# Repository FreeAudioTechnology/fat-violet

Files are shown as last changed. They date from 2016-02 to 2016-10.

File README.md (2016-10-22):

# violet
Open Source Microphone System with integrated ADC, digital phantom power, AES42, large diaphragm condenser capsule support

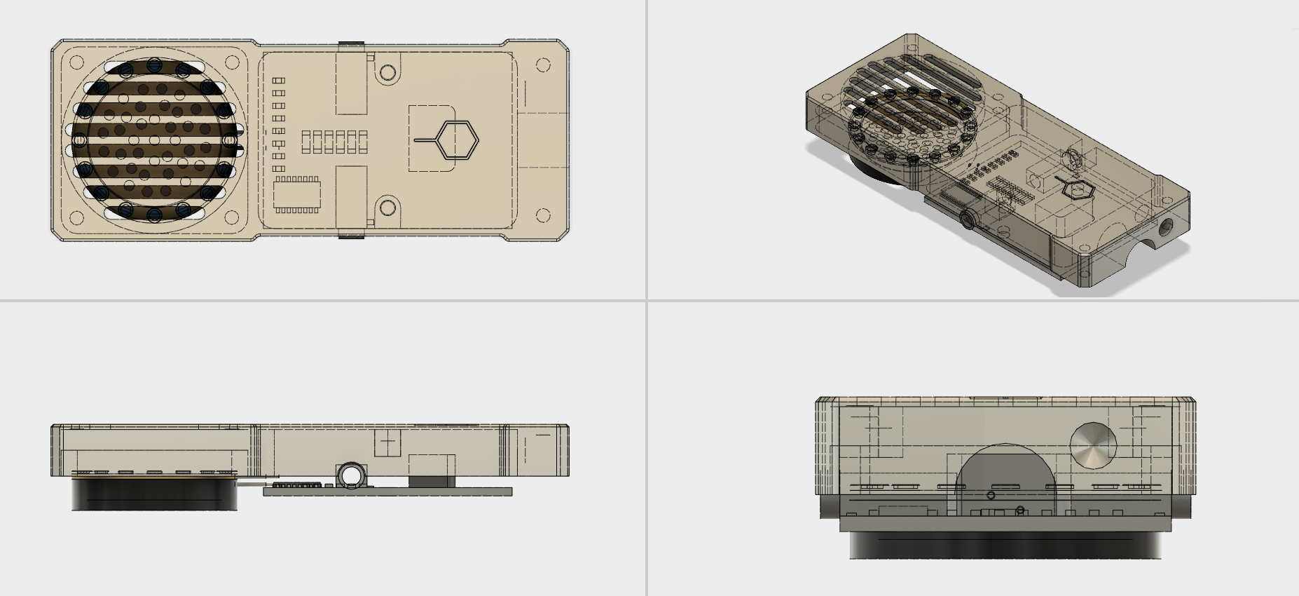
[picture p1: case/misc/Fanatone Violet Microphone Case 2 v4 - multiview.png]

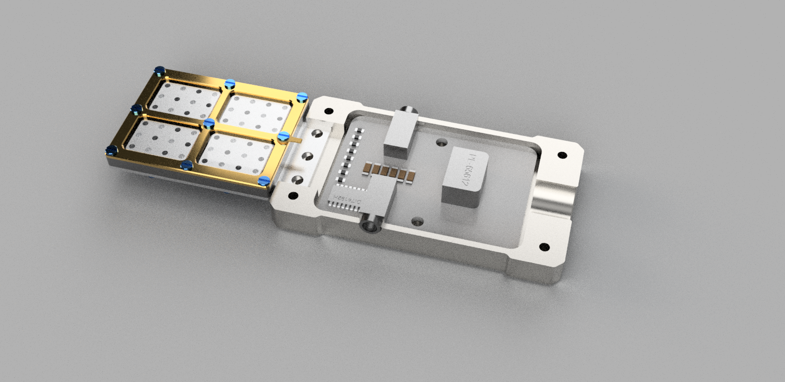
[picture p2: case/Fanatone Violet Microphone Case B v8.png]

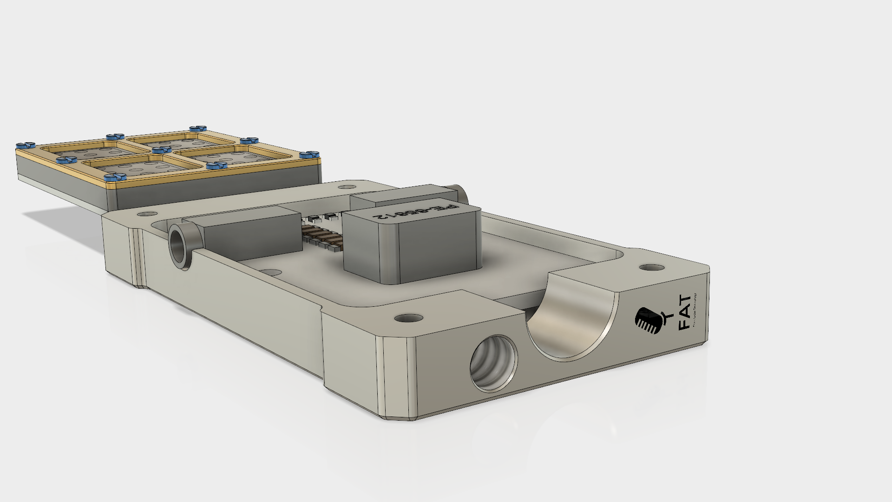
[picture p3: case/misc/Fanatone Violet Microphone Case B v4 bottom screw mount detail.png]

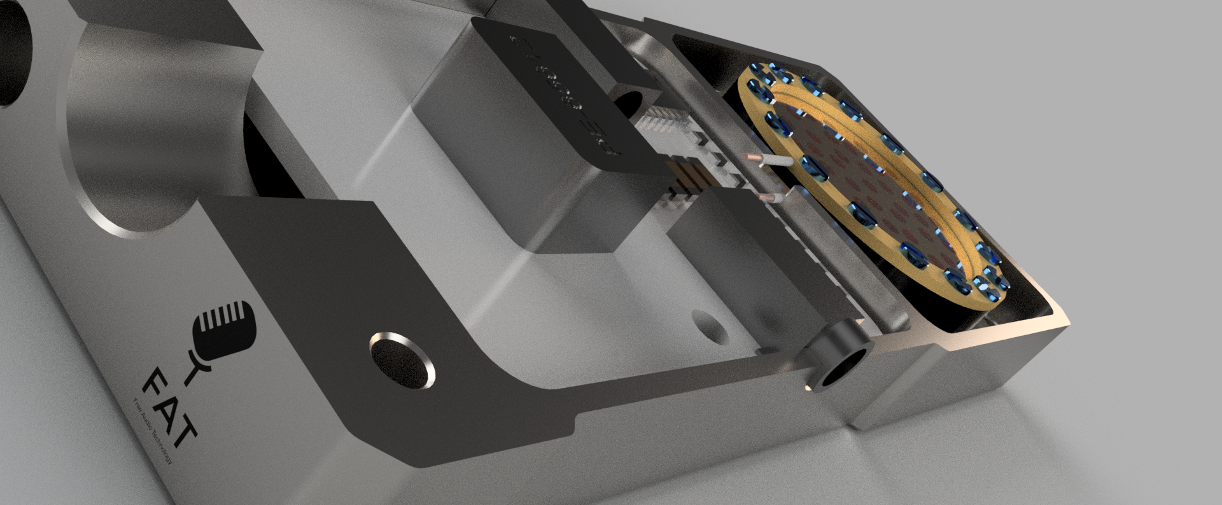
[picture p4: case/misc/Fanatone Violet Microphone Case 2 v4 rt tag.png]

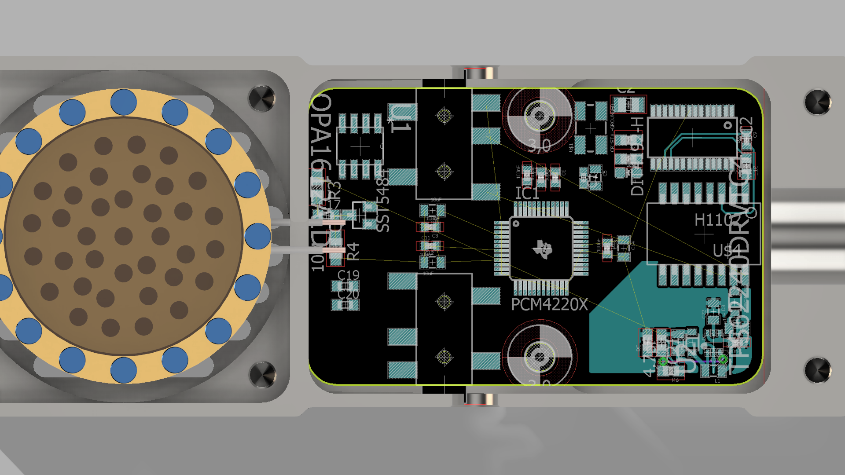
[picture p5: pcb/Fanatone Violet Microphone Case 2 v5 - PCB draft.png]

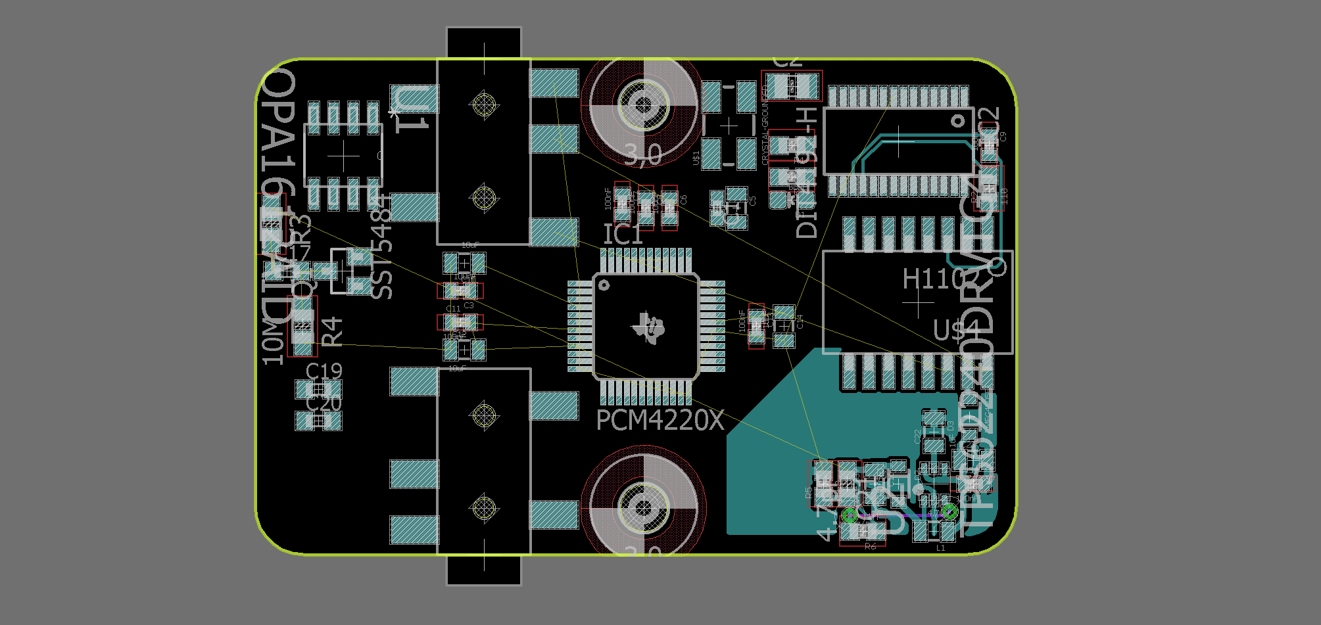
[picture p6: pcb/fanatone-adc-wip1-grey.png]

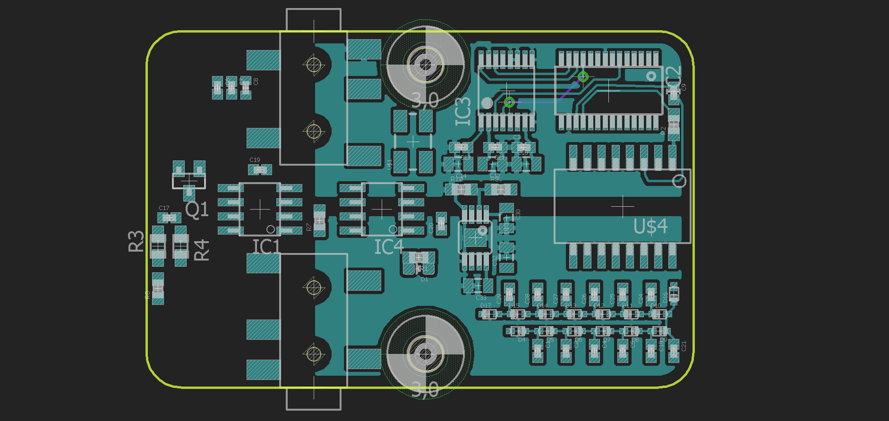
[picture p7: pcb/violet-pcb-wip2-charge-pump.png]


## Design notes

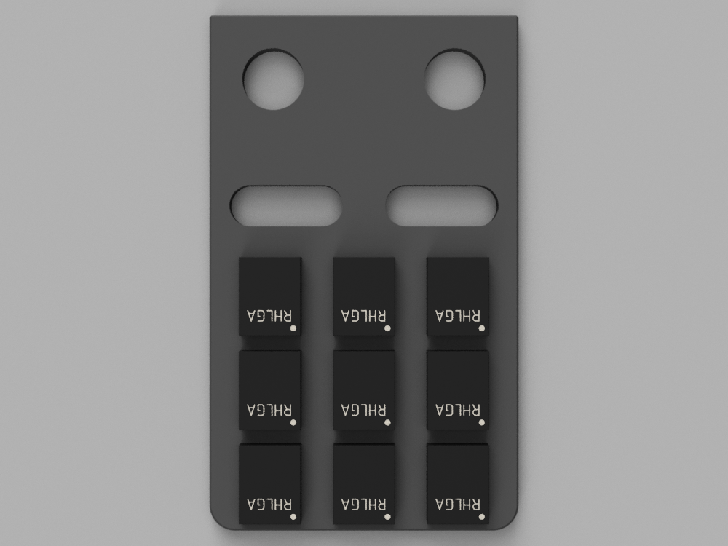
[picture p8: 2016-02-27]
capsule/FAT array A/FAT_MEMS_Array_A1_2016-Feb-26_02-34-16AM-000_TOP.png

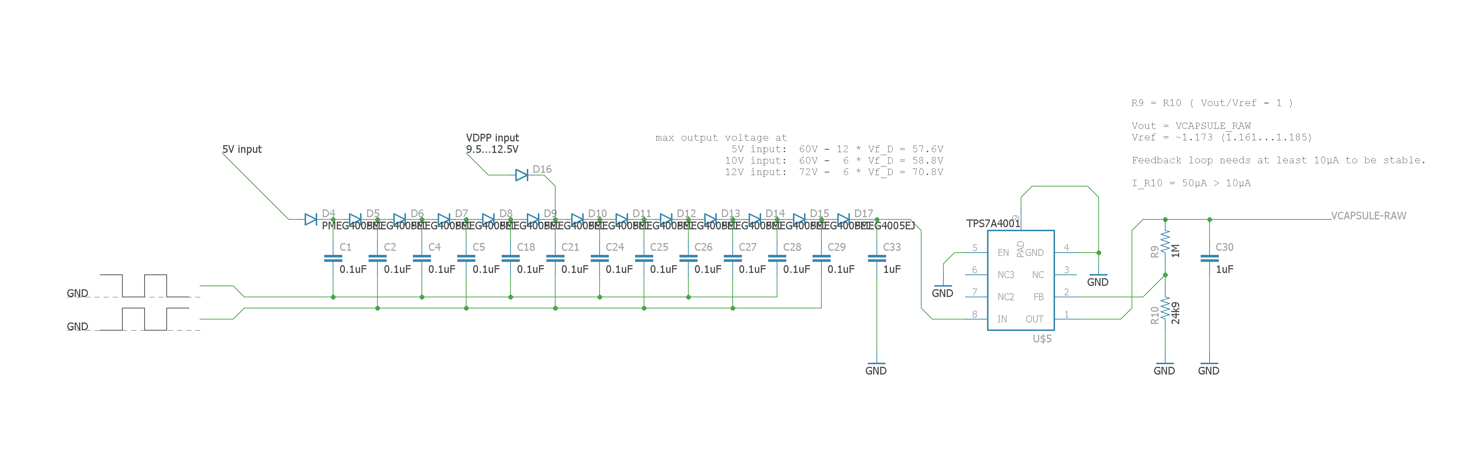
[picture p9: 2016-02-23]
pcb/ChargePump-TPS7A4001.png

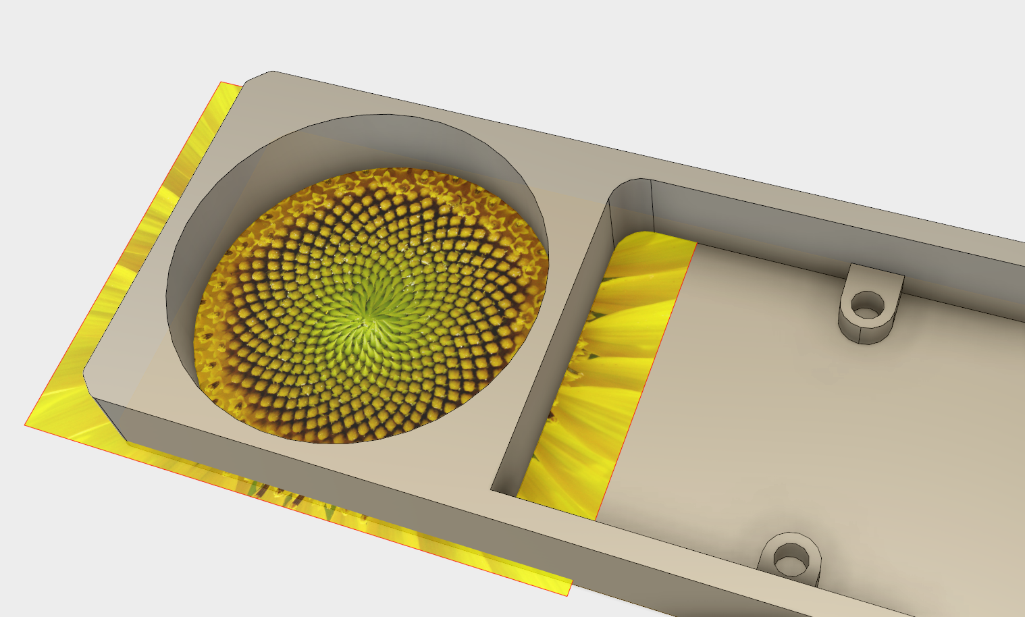
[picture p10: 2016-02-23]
case/misc/Fanatone Violet Microphone Case 1 v7 fibonacci sunflower.png

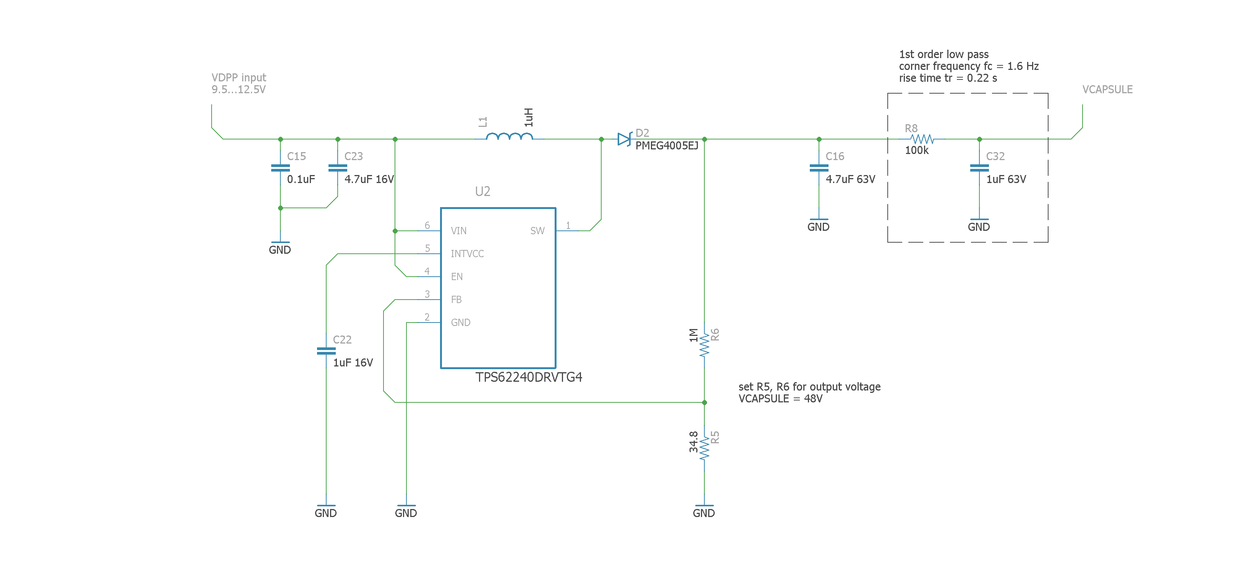
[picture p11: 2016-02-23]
pcb/BoostConverterTPS62240.png

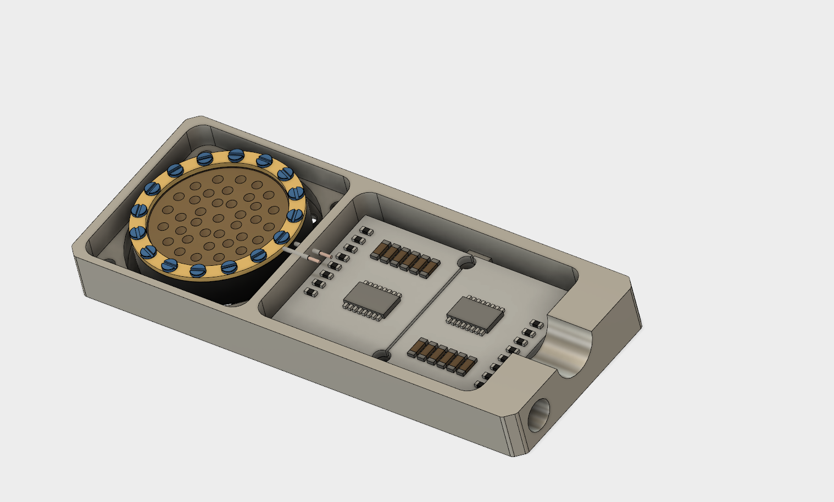
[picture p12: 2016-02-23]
case/misc/Fanatone Violet Microphone Case 1 v10.png

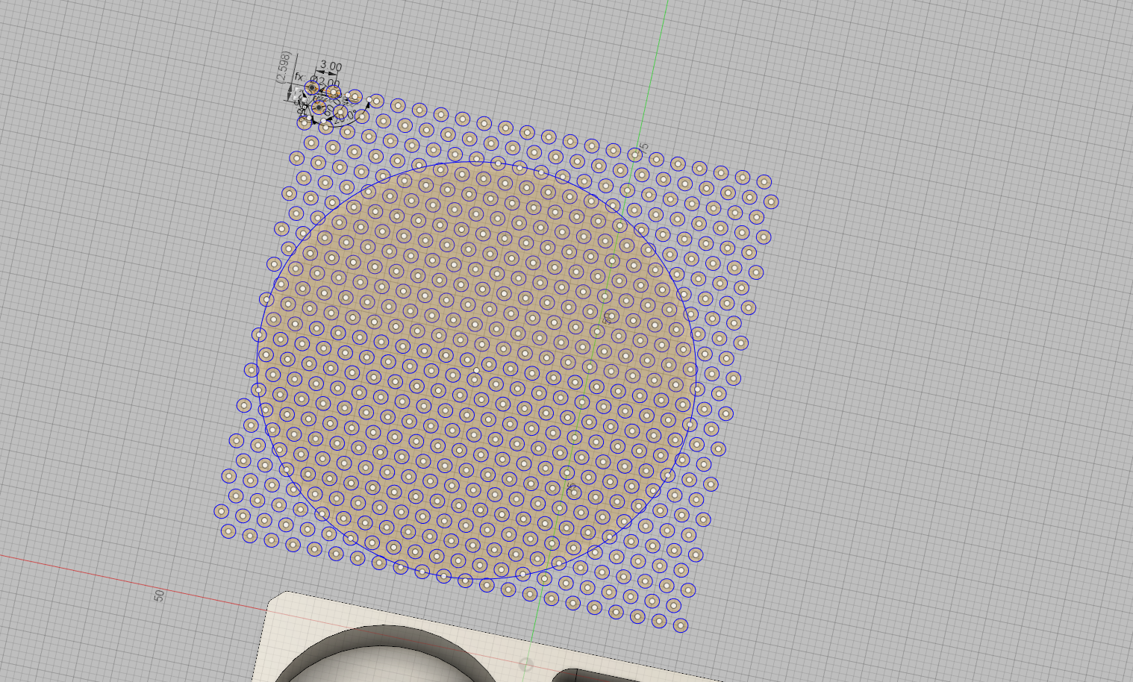
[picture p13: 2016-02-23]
case/misc/Fanatone Violet Microphone Case 1 v8 hole pattern 2.png

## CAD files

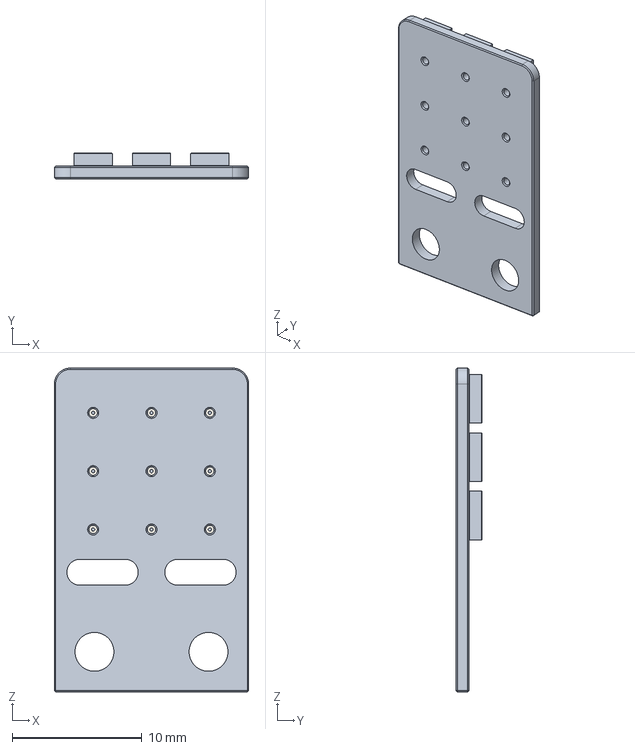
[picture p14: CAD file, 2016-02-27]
capsule/FAT array A/FAT MEMS Array A1 v2.step
15.0 x 2.00 x 25.0 mm

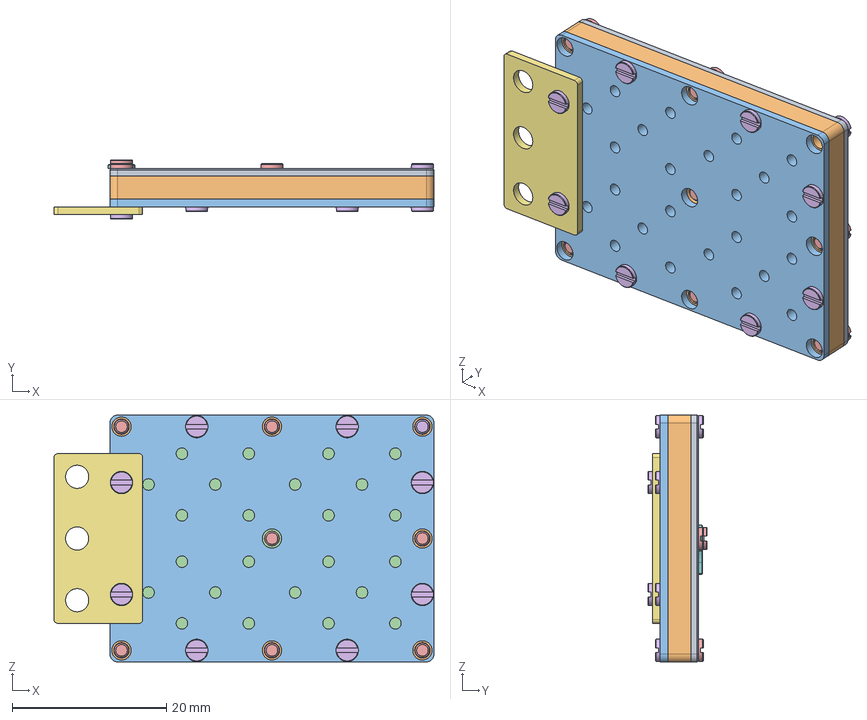
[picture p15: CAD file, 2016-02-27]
capsule/FAT capsule R/FAT Capsule R v9.step
49.2 x 7.70 x 32.0 mm
top clamp (brass)
base (POM)
back electrode (7075)
diaphragm
top screws
bottom screws2
mounting plate
wire connector

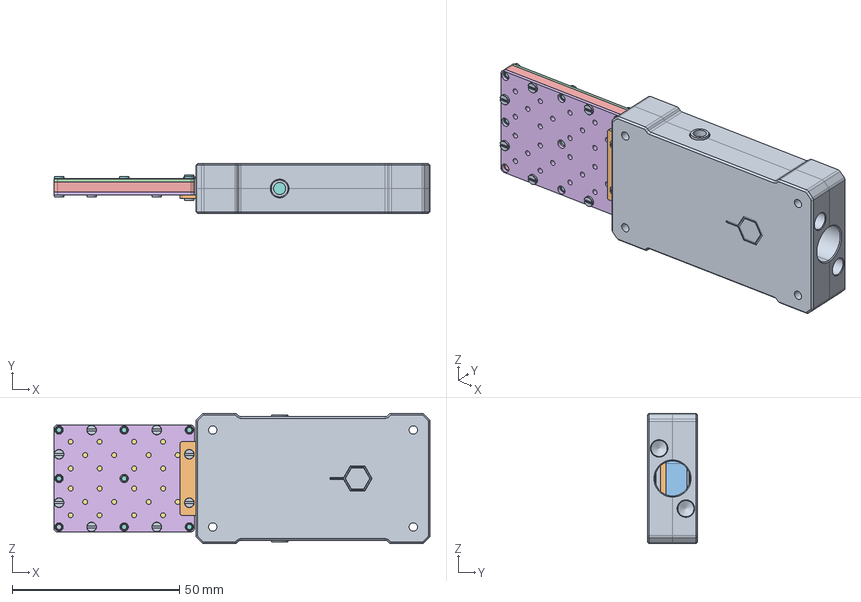
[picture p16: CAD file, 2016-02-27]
case/Fanatone Violet Microphone Case B v8.step
112.5 x 15.0 x 39.0 mm
Housing x 2
PCB
top clamp (brass)
base (POM)
back electrode (7075)
diaphragm
top screws
bottom screws2
mounting plate
wire connector

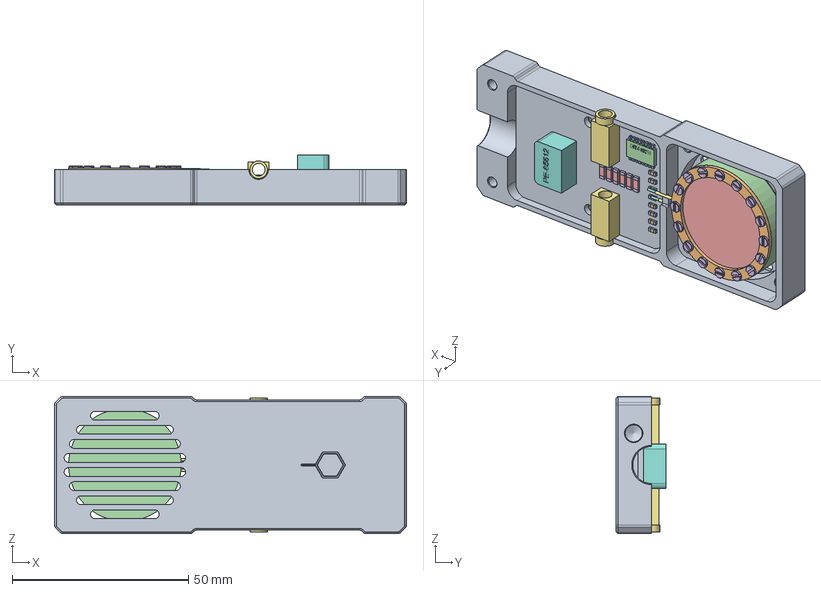
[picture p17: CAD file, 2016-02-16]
case/misc/FAT Violet Microphone Case A 2 v5.step
100.0 x 14.2 x 39.0 mm
Housing
Top Ring
base
Diaphragm
PCB

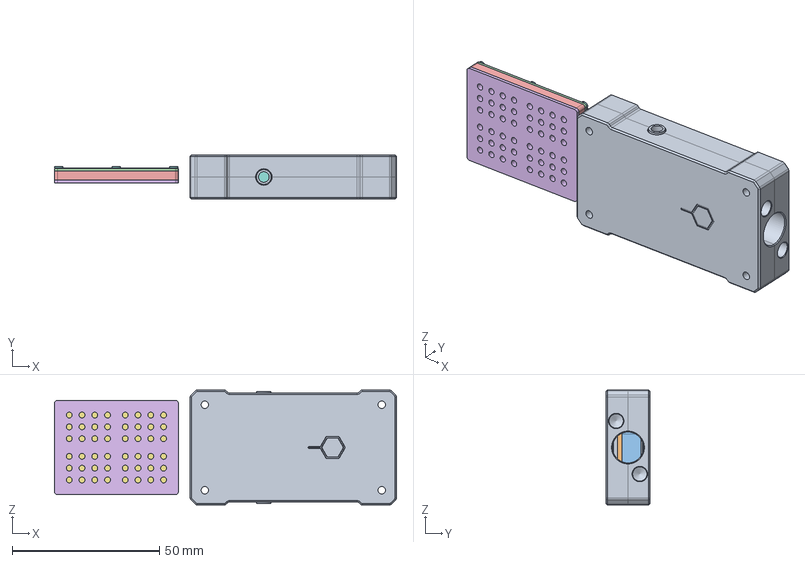
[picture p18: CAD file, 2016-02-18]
case/FAT Violet Microphone Case B v2.step
116.0 x 15.0 x 39.0 mm
Housing x 2
PCB
top clamp
base
back electrode
diaphragm

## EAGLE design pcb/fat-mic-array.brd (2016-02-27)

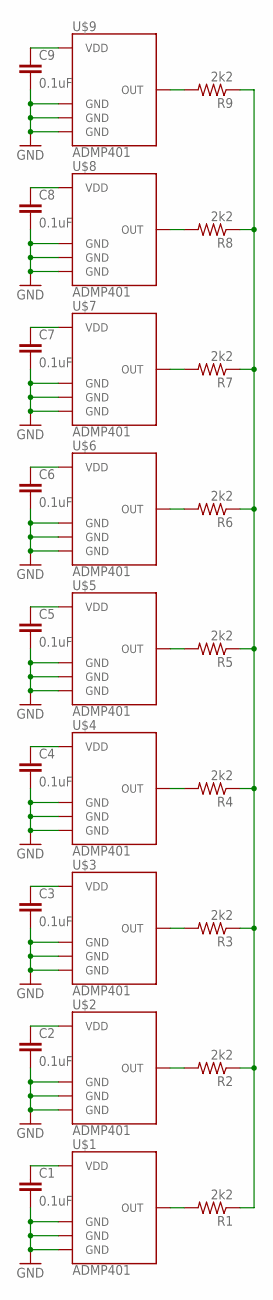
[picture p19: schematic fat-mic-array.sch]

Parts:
C1, C2, C3, C4, C5, C6, C7, C8, C9: 0.1uF; 0402-CAP
R1, R2, R3, R4, R5, R6, R7, R8, R9: 2k2; 0402-RES
U$1, U$2, U$3, U$4, U$5, U$6, U$7, U$8, U$9: ADMP401

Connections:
GND: C1.2, C2.2, C3.2, C4.2, C5.2, C6.2, C7.2, C8.2, C9.2, U$1.2 (GND), U$1.4 (GND), U$1.6 (GND), U$2.2 (GND), U$2.4 (GND), U$2.6 (GND), U$3.2 (GND), U$3.4 (GND), U$3.6 (GND), U$4.2 (GND), U$4.4 (GND), U$4.6 (GND), U$5.2 (GND), U$5.4 (GND), U$5.6 (GND), U$6.2 (GND), U$6.4 (GND), U$6.6 (GND), U$7.2 (GND), U$7.4 (GND), U$7.6 (GND), U$8.2 (GND), U$8.4 (GND), U$8.6 (GND), U$9.2 (GND), U$9.4 (GND), U$9.6 (GND)
unnamed: R1.2, U$1.1 (OUT)
unnamed: C1.1, U$1.5 (VDD)
unnamed: R3.2, U$3.1 (OUT)
unnamed: R1.1, R2.1, R3.1, R4.1, R5.1, R6.1, R7.1, R8.1, R9.1
unnamed: R2.2, U$2.1 (OUT)
unnamed: C2.1, U$2.5 (VDD)
unnamed: C3.1, U$3.5 (VDD)
unnamed: R4.2, U$4.1 (OUT)
unnamed: C4.1, U$4.5 (VDD)
unnamed: R5.2, U$5.1 (OUT)
unnamed: C5.1, U$5.5 (VDD)
unnamed: R6.2, U$6.1 (OUT)
unnamed: C6.1, U$6.5 (VDD)
unnamed: R7.2, U$7.1 (OUT)
unnamed: C7.1, U$7.5 (VDD)
unnamed: R8.2, U$8.1 (OUT)
unnamed: C8.1, U$8.5 (VDD)
unnamed: R9.2, U$9.1 (OUT)
unnamed: C9.1, U$9.5 (VDD)

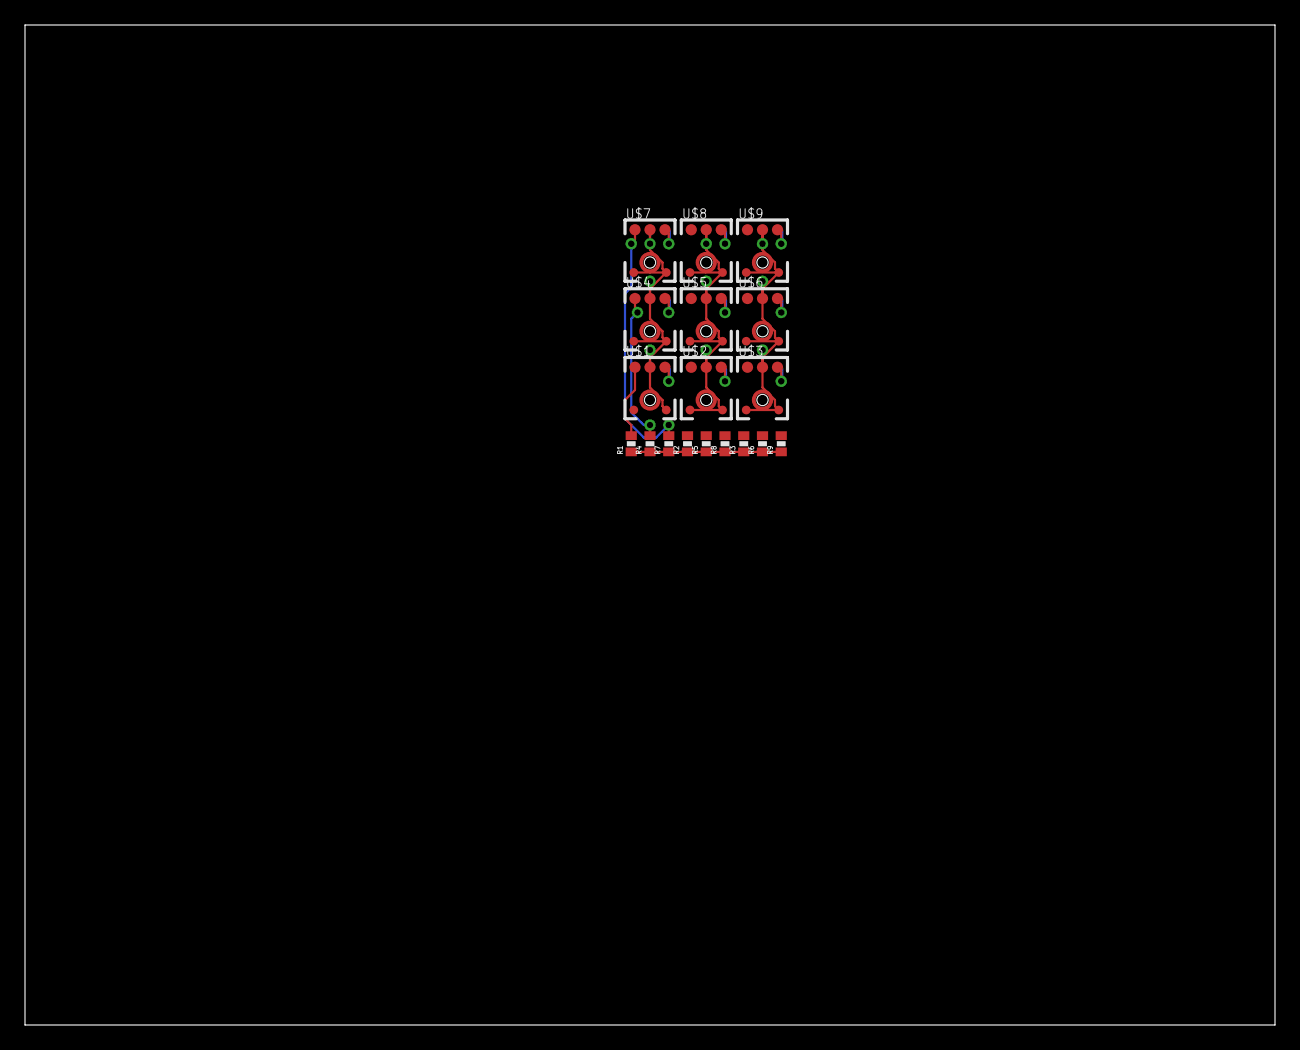
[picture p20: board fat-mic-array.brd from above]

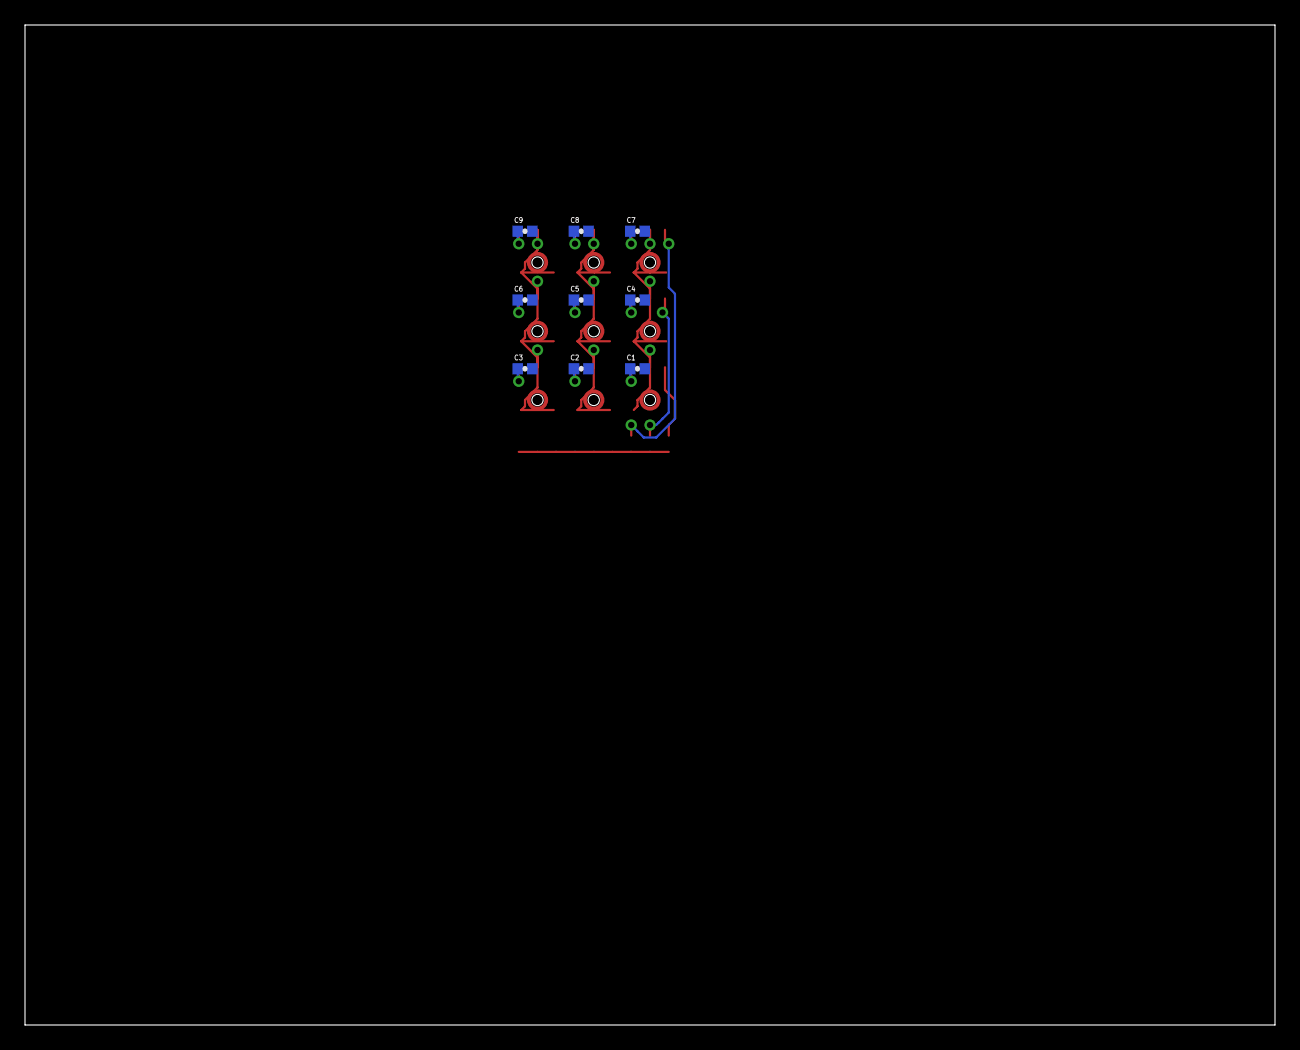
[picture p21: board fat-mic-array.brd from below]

Board: 2 copper layers, 100.0 x 80.0 mm, 27 parts (9 on the bottom side), 20 nets.

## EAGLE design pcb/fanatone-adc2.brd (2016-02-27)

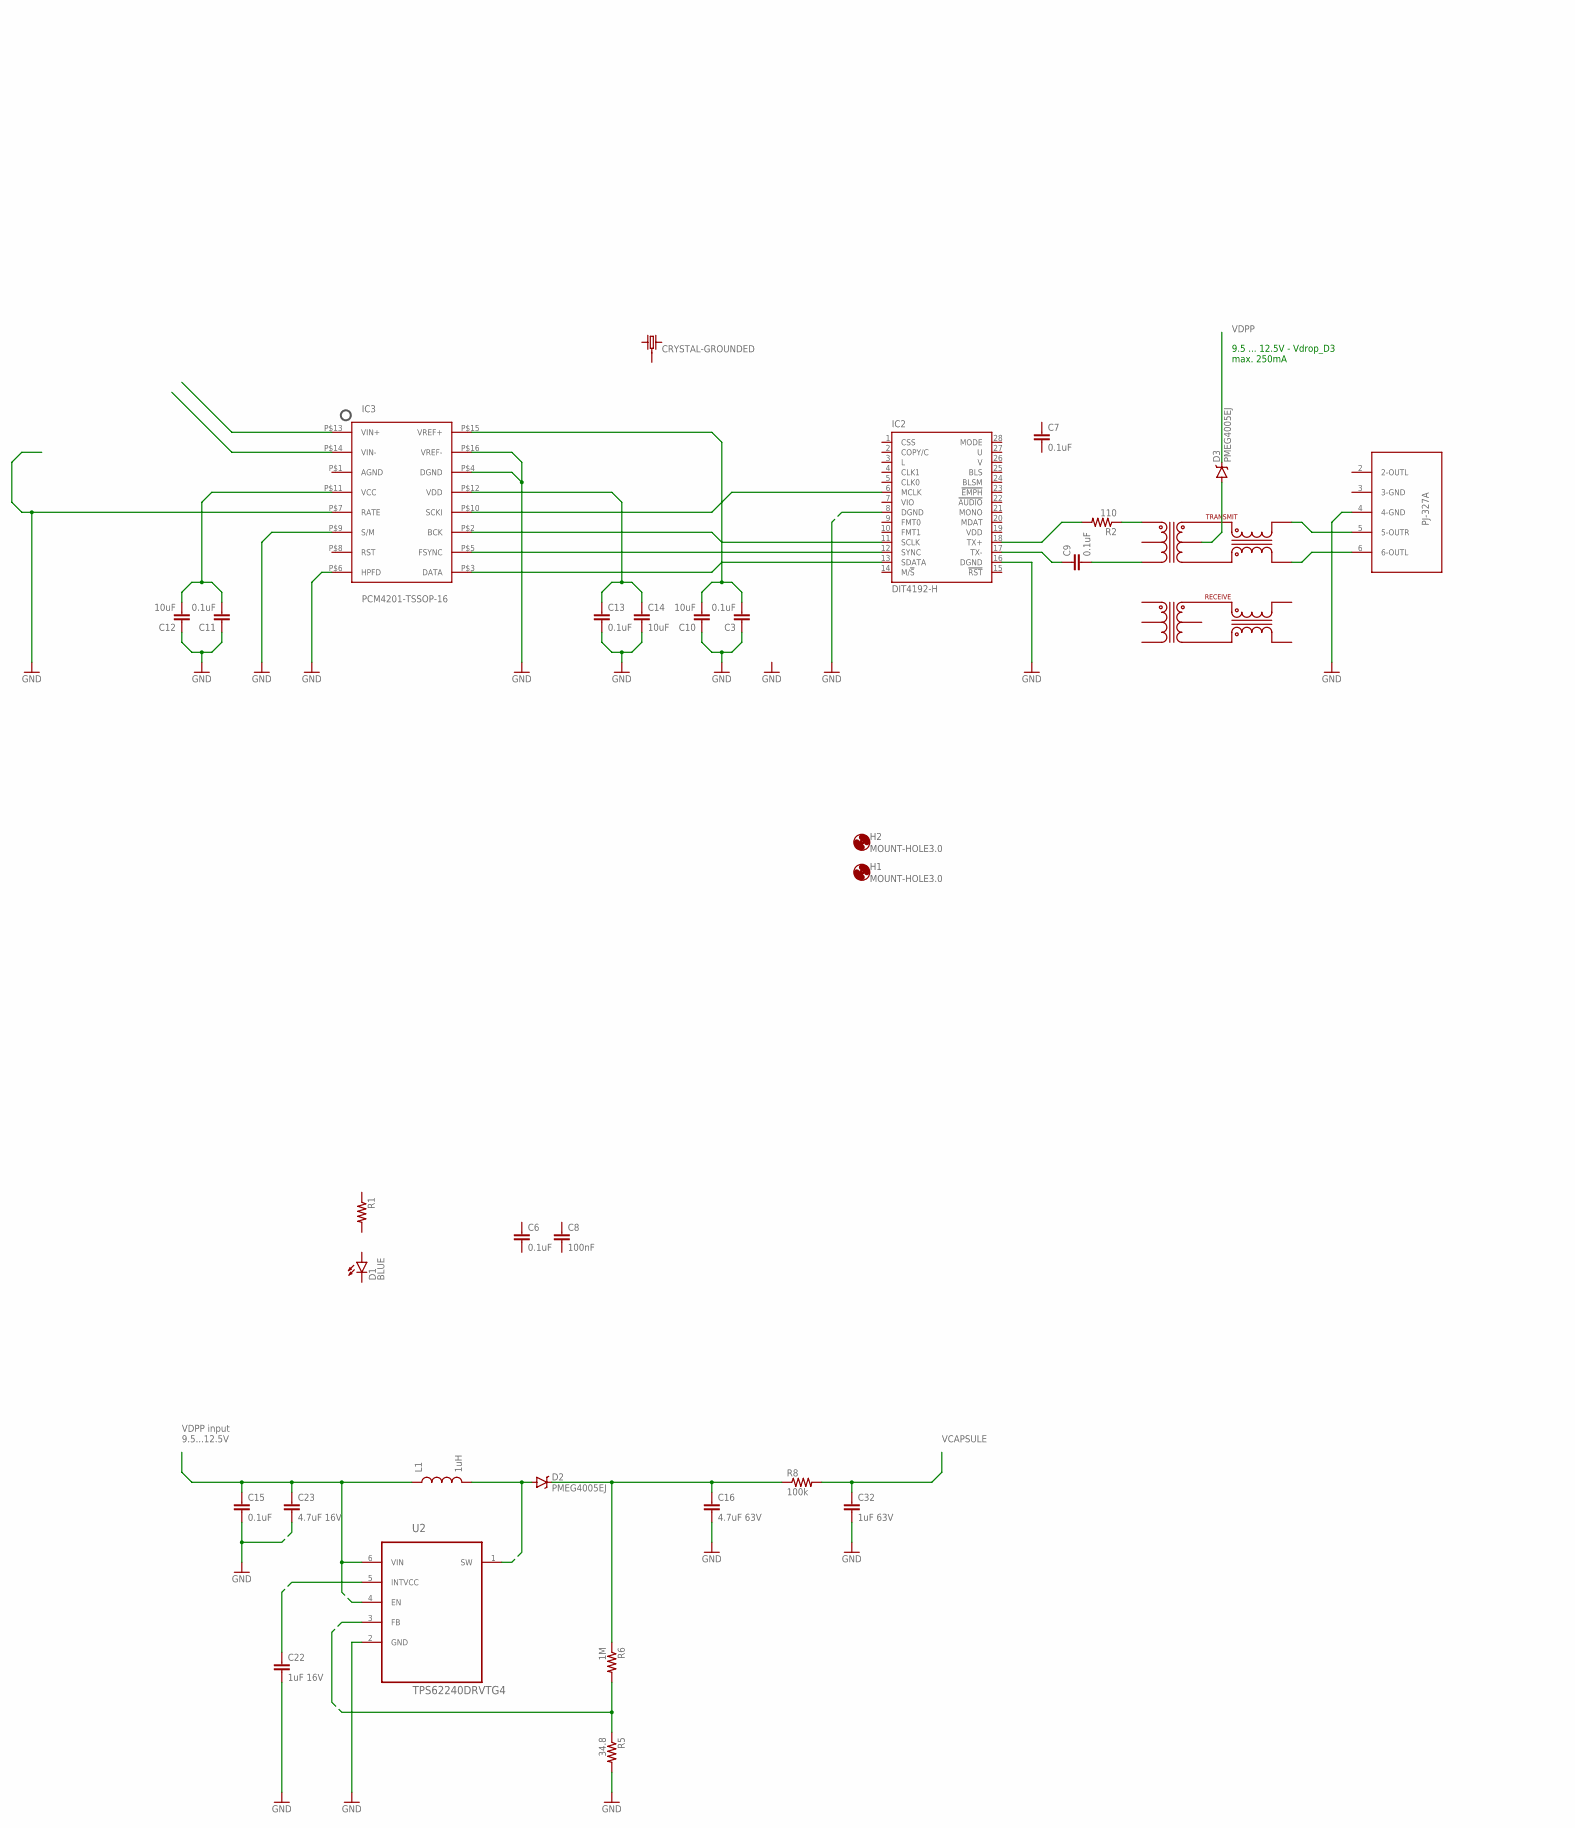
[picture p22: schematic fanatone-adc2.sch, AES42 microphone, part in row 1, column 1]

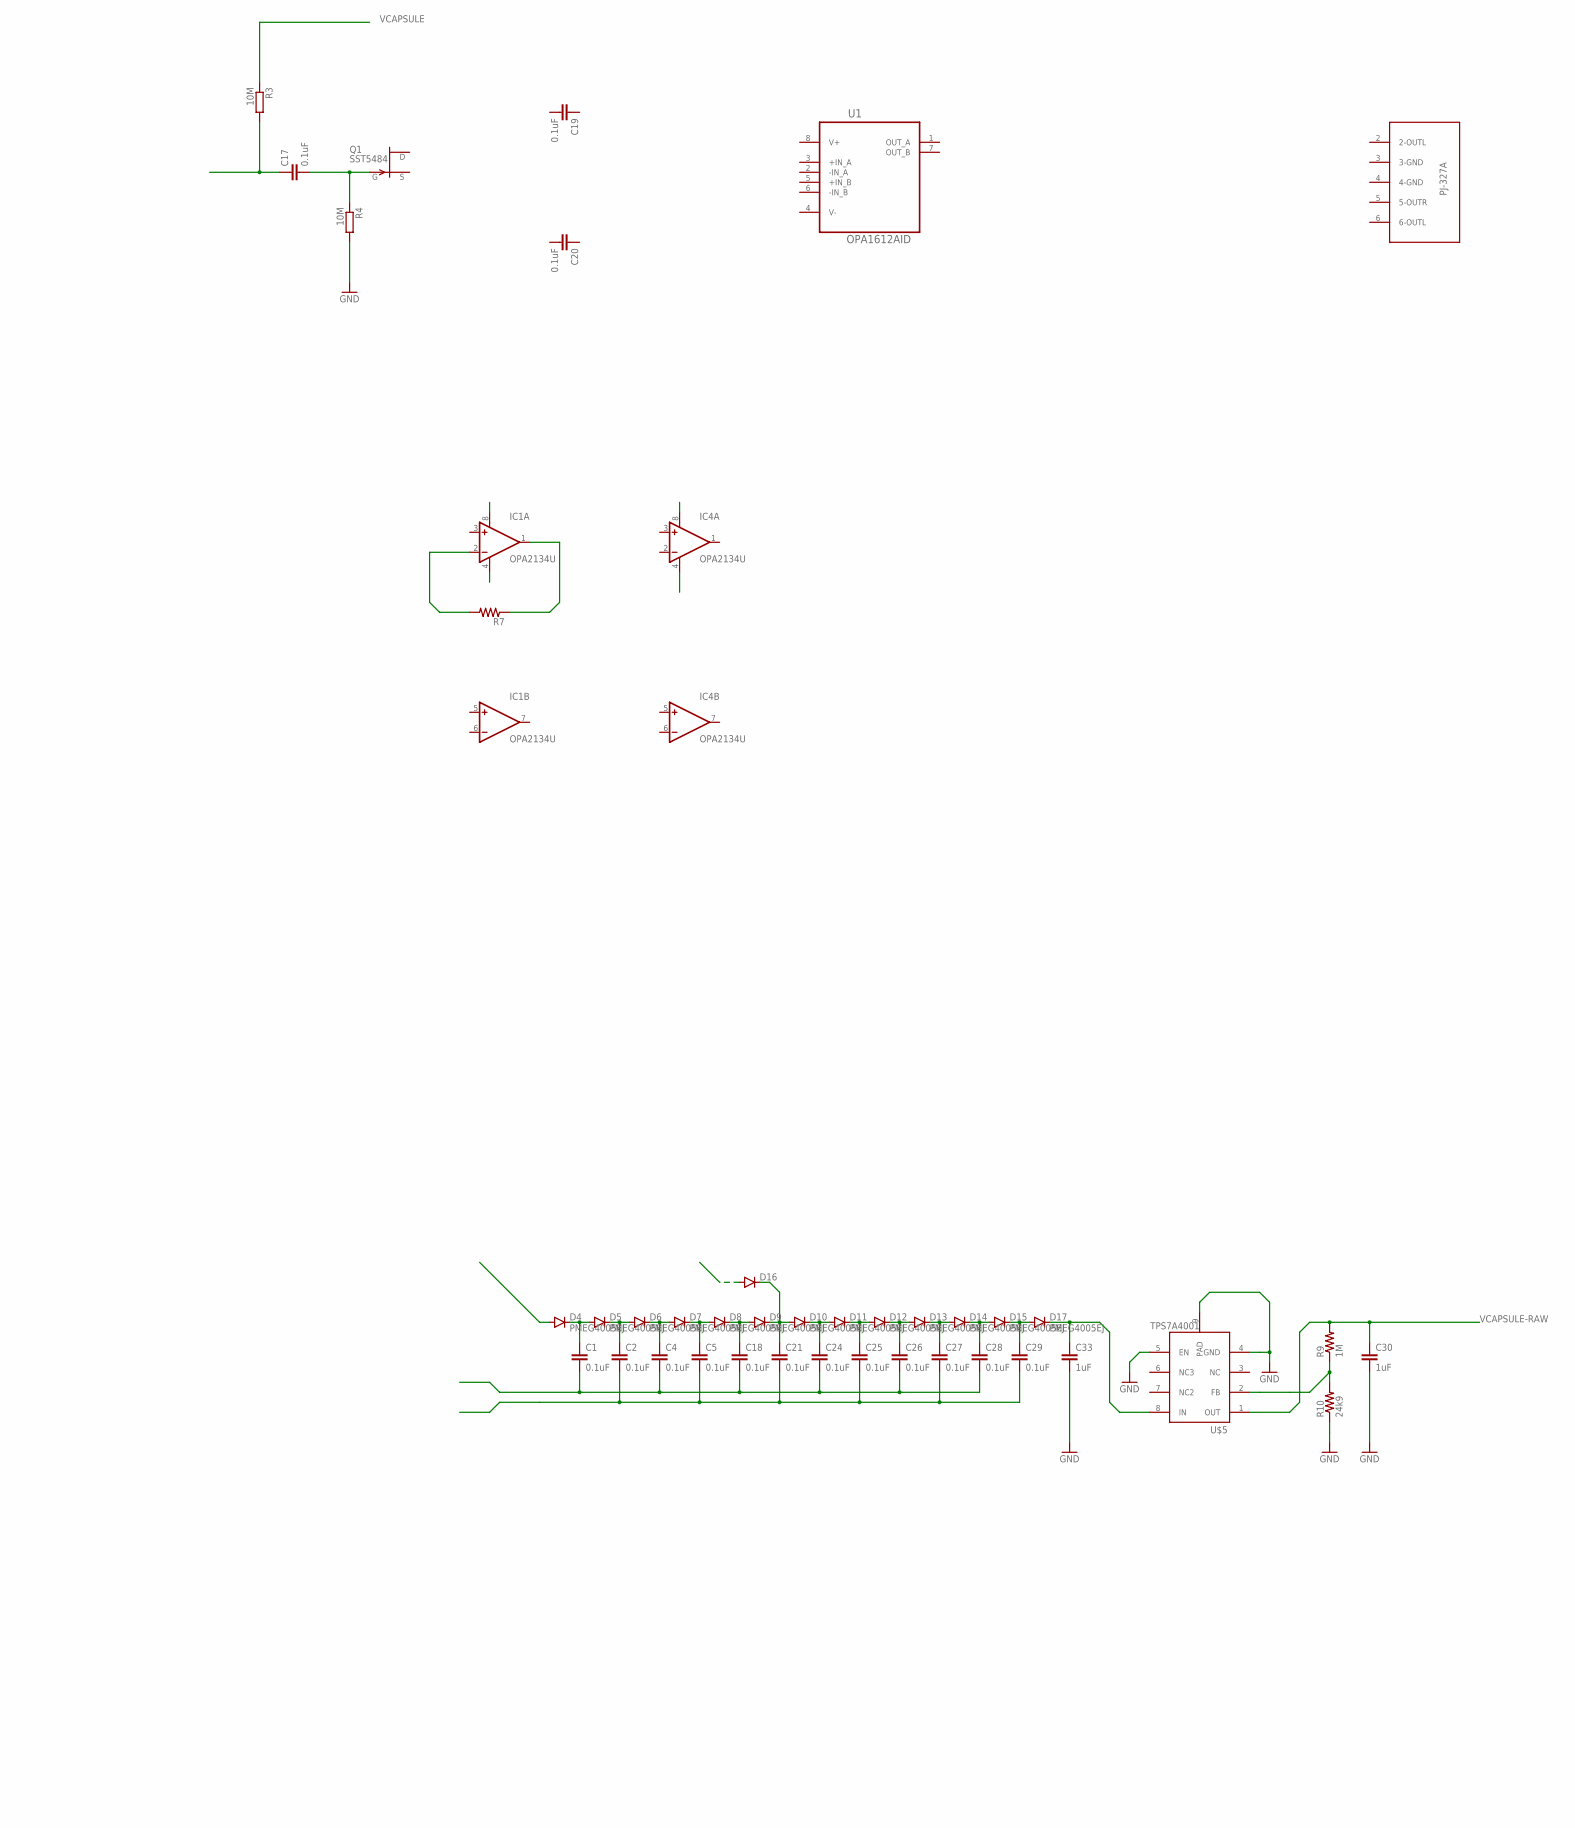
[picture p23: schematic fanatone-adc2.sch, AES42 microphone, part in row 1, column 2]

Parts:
C1, C2, C3, C4, C5, C6, C7, C9, C11, C13, C15, C17, C18, C19, C20, C21, C24, C25, C26, C27, C28, C29: 0.1uF; 0402-CAP
C8: 100nF; 0402-CAP
C10, C12, C14: 10uF; 0805
C16: 4.7uF 63V; 0805
C22: 1uF 16V; 0805
C23: 4.7uF 16V; 0805
C30, C33: 1uF; 0805
C32: 1uF 63V; 0805
D1: BLUE; LED-0603
D2, D3: PMEG4005EJ; SOD-323
D4, D5, D6, D7, D8, D9, D10, D11, D12, D13, D14, D15, D17: PMEG4005EJ; SOD523
D16: DIODESOD523; SOD523
H1, H2: MOUNT-HOLE3.0; 3,0
IC1, IC4: OPA2134U; SO08
IC2: DIT4192-H; PW_R-PDSO-G28
IC3: PCM4201-TSSOP-16; TSSOP-16
L1: 1uH; 0805
Q1: SST5484; SOT23
R1, R7: RESISTOR0603-RES; 0603-RES
R2: 110; 0603-RES
R3, R4: 10M; R0805W
R5: 34.8; 0603-RES
R6, R9: 1M; 0603-RES
R8: 100k; 0603-RES
R10: 24k9; 0603-RES
U1: OPA1612AID; SOIC127P600X175-8N
U2: TPS62240DRVTG4; SON65P210X210X80-7N
U$1: CRYSTAL-GROUNDED; CRYSTAL-SMD-5X3
U$2, U$3: PJ-327A
U$4: H1102; H11XX
U$5: TPS7A4001; POWER-SOP8

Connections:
3V3: C13.1, C14.1, IC3.P$12 (VDD)
5V: C11.2, C12.2, IC3.P$11 (VCC)
GND: C3.1, C10.1, C11.1, C12.1, C13.2, C14.2, C15.2, C16.2, C22.2, C23.2, C30.2, C32.2, C33.2, IC2.8 (DGND), IC2.16 (DGND), IC3.P$4 (DGND), IC3.P$6 (HPFD), IC3.P$7 (RATE), IC3.P$9 (S/M), IC3.P$16 (VREF-), R4.2, R5.2, R10.1, U2.2 (GND), U$2.4 (4-GND), U$5.4 (GND), U$5.5 (EN), U$5.9 (PAD)
unnamed: C9.2, U$4.3
unnamed: R2.1, U$4.1
unnamed: C17.1, R3.2
unnamed: C17.2, Q1.3 (G), R4.1
unnamed: C3.2, C10.2, IC3.P$15 (VREF+)
unnamed: IC2.18 (TX+), R2.2
unnamed: R5.1, R6.2, U2.3 (FB)
unnamed: C22.1, U2.5 (INTVCC)
unnamed: C9.1, IC2.17 (TX-)
unnamed: D3.A, U$4.15
unnamed: D2.A, L1.2, U2.1 (SW)
unnamed: IC2.11 (SCLK), IC3.P$2 (BCK)
unnamed: C4.1, D6.C, D7.A
unnamed: IC2.12 (SYNC), IC3.P$5 (FSYNC)
unnamed: IC2.13 (SDATA), IC3.P$3 (DATA)
unnamed: U$2.6 (6-OUTL), U$4.14
unnamed: IC2.6 (MCLK), IC3.P$10 (SCKI)
unnamed: U$2.5 (5-OUTR), U$4.16
unnamed: IC1.1 (OUT), R7.1
unnamed: IC1.2 (-IN), R7.2
unnamed: C1.1, D4.C, D5.A
unnamed: C1.2, C4.2, C18.2, C24.2, C26.2, C28.2
unnamed: C2.1, D5.C, D6.A
unnamed: C2.2, C5.2, C21.2, C25.2, C27.2, C29.2
unnamed: C29.1, D15.C, D17.A
unnamed: C5.1, D7.C, D8.A
unnamed: R9.1, R10.2, U$5.2 (FB)
unnamed: C18.1, D8.C, D9.A
unnamed: C21.1, D9.C, D10.A, D16.C
unnamed: C24.1, D10.C, D11.A
unnamed: C25.1, D11.C, D12.A
unnamed: C26.1, D12.C, D13.A
unnamed: C27.1, D13.C, D14.A
unnamed: C28.1, D14.C, D15.A
unnamed: C33.1, D17.C, U$5.8 (IN)
V+: U1.8 (V+)
V-: U1.4 (V-)
VCAPSULE: C32.1, R3.1, R8.2
VCAPSULE-RAW: C16.1, C30.1, D2.C, R6.1, R8.1, R9.2, U$5.1 (OUT)
VDD: IC2.19 (VDD)
VDPP: C15.1, C23.1, D3.C, D16.A, L1.1, U2.4 (EN), U2.6 (VIN)
VIO: IC2.7 (VIO)

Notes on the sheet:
9.5 ... 12.5V - Vdrop_D3 max. 250mA
VDPP input 9.5...12.5V

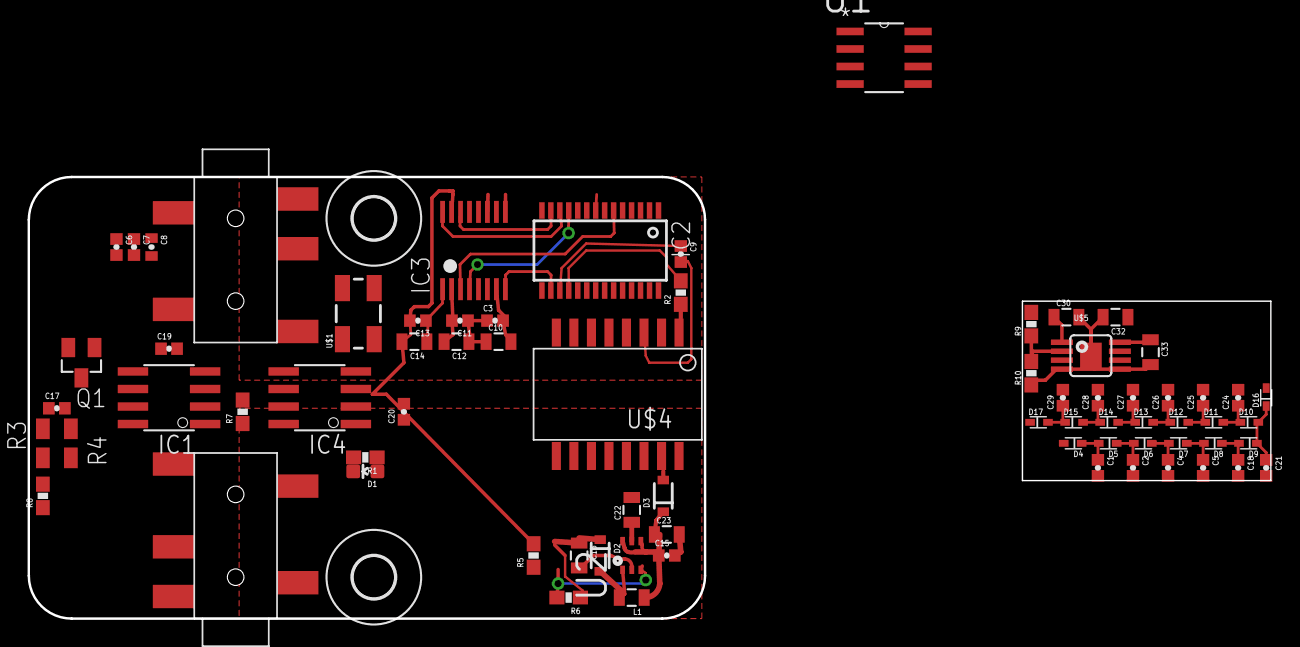
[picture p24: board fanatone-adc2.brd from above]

Board: 2 copper layers, 90.0 x 32.0 mm, 74 parts (0 on the bottom side), 41 nets.

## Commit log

2016-02-16 add Eagle PCB src files WIP
    [fanatone-adc.brd, fanatone-adc.sch]
2016-02-16 add datasheets, remove capacitor over R6 at booster
    [fanatone-adc.brd, fanatone-adc.sch]
2016-02-16 step file exported from Fusion 360
    [Fanatone Violet Microphone Case 2 v5.step]
2016-02-18 Rectangular FAT Capsule R design
    [Fanatone Violet Microphone Case B v2.step, fanatone-adc.brd, fanatone-adc.sch]
2016-02-18 correct naming scheme, +animated exploded view
    [FAT Violet Microphone Case A 2 v5.step, FAT Violet Microphone Case B v2.step, Fanatone Violet Microphone Case 2 v5.step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]
2016-02-19 start with OPA2134 at the initial gain stage
    [fanatone-adc.brd, fanatone-adc.sch]
2016-02-22 evaluating DC charge pump/multiplier layouts
    [fanatone-adc2.brd, fanatone-adc2.sch]
2016-02-23 Dickson charge pump layout, PCB wip, tidy up
    [FAT Violet Microphone Case A 2 v5.step, fanatone-adc2.brd, fanatone-adc2.sch]
2016-02-27 add concept for a MEMS Microphone array + step file sync + animation
    [FAT Capsule R v9.step, FAT MEMS Array A1 v2.step, Fanatone Violet Microphone Case B v8.step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]

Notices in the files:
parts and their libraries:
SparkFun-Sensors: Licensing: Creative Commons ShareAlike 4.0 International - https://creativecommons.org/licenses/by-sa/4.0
